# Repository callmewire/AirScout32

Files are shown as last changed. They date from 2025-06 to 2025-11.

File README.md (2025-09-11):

# AirScout32 - Mobile Air Quality Monitoring System

A complete open-source air quality monitoring solution combining ESP32-based hardware sensors with an Android application for real-time data visualization and analysis.

## 🌟 Project Overview

AirScout32 is a cost-effective, portable air quality measurement device developed as part of a Bachelor's thesis in Media Informatics. The system addresses the gap between expensive professional equipment and basic consumer devices by providing reliable multi-parameter air quality monitoring for under €100.

**Project Name**: AirScout32 reflects three core aspects:
- **Air**: Focus on air quality measurement
- **Scout**: Mobile reconnaissance and warning functionality  
- **32**: Based on the ESP32 microcontroller platform

## 📁 Repository Structure
```
AirScout32/
├── android-app/          # Android application source code
├── firmware/             # ESP32 Arduino firmware
├── hardware/             # 3D models, schematics, and assembly guides
├── docs/                 # Documentation and user manuals
└── README.md            # This file
```

## 🔧 Hardware Components

### Sensors
- **SCD40**: CO₂ measurement (400-5000 ppm) via NDIR technology
- **MiCS-5524**: VOC/CO detection with baseline calibration
- **Integrated**: Temperature and humidity monitoring

### Core System
- **ESP32 DevKit**: Dual-core microcontroller with Bluetooth/WiFi
- **18650 Li-Ion**: 8-10 hour battery life with charging management
- **Custom Enclosure**: 3D-printed dual-chamber design for thermal isolation

### Key Features
- **Autonomous alarms**: Independent safety warnings without smartphone
- **Transport stable**: No recalibration needed after movement
- **External mounting**: Prevents measurement interference from user breathing
- **Modular design**: Easy sensor expansion via I2C/analog interfaces

## 📱 Android Application

### Real-time Monitoring
- Live data visualization with interactive charts
- Bluetooth connectivity via Classic Bluetooth (SPP)
- Current values for all sensor parameters and battery status
- Configurable chart limits for performance optimization

### Session Management
- Session-based data collection with custom names
- Complete data storage independent of chart display limits
- CSV export for scientific analysis
- Metadata capture (start time, duration, data point count)

### Flexible Configuration
- Dynamic JSON mapping for different ESP32 sensor configurations
- Customizable parameter names without app recompilation
- Chart data point limitation (50-1000 points)
- User-friendly settings interface

## 🏗️ Technical Architecture

### Hardware-Software Integration
```
ESP32 Sensors → Bluetooth → Android App → Local Database → CSV Export
```

### Communication Protocol
- **Bluetooth Classic (SPP)**: Reliable connection for mobile use
- **JSON data format**: Human-readable and extensible
- **5-second intervals**: Balance between responsiveness and battery life

### Android MVVM Pattern
```
View (Fragments) ↔ ViewModel ↔ Repository (Database + Bluetooth)
```

## 📊 Supported Measurements

### Air Quality Parameters
- **CO₂**: 400-5000 ppm (±50 ppm accuracy)
- **VOCs**: Relative to baseline (MOX sensor)
- **CO**: 1-1000 ppm detection range
- **Temperature**: Integrated environmental monitoring
- **Humidity**: Relative humidity measurement

### Standard JSON Format
```json
{
  "tmp": 25.5,
  "hum": 60.2,
  "gas1": 450,
  "gas2": 320,
  "akku": 3.7
}
```

## 🚀 Getting Started

### Hardware Setup
1. **3D print enclosure** using provided STL files
2. **Assemble electronics** following wiring diagram
3. **Flash firmware** using Arduino IDE
4. **Calibrate sensors** in clean air environment

### Software Setup
1. **Install Android app** from releases or build from source
2. **Pair ESP32** in Android Bluetooth settings
3. **Configure JSON mapping** according to sensor setup
4. **Connect and start monitoring**

### Quick Start
1. Power on AirScout32 device
2. Open Android app and connect via Bluetooth
3. Monitor real-time values in Realtime tab
4. Save measurement sessions for later analysis
5. Export data as CSV for scientific evaluation

## 🔬 Scientific Applications

### Use Cases
- **Indoor air quality assessment** in homes and offices
- **Renovation monitoring** for VOC emissions
- **Workplace safety** in industrial environments
- **Educational demonstrations** of air quality concepts
- **Research data collection** for environmental studies

### Research Contributions
- Cost-effective multi-parameter air quality monitoring
- Mobile sensor platform with transport stability
- Open-source design for reproducible research
- Modular architecture for custom sensor integration

## 💾 Data Management

### Export Features
- Session metadata in CSV headers
- Timestamps in Unix and human-readable formats
- All parameters including battery status
- Android sharing for direct data transfer

### Privacy & Security
- Local data storage only (no cloud dependency)
- User-controlled data export
- Minimal permission requirements

## 📈 Performance & Reliability

### Battery Life
- **8-10 hours** continuous operation
- **2.5 hours** charging time
- **Intelligent power management**

### Measurement Accuracy
- **Factory-calibrated sensors** for CO₂
- **Baseline calibration** for relative VOC measurements
- **Transport-stable** readings without recalibration

### Build Quality
- **Dual-chamber design** prevents thermal interference
- **Heat-set inserts** for professional assembly
- **IP54-rated** for normal indoor use

## 🛠️ Development

### Building Android App
```bash
# Clone repository
git clone https://github.com/username/AirScout32
cd AirScout32/android-app

# Build debug APK
./gradlew assembleDebug

# Run tests
./gradlew test
```

### Flashing ESP32 Firmware
```bash
# Open firmware/AirScout32.ino in Arduino IDE
# Install required libraries (listed in firmware/README.md)
# Select ESP32 board and flash
```

### 3D Printing
- **Material**: PETG recommended for final version
- **Settings**: 0.2mm layer height, 30% infill
- **Post-processing**: Install heat-set inserts for assembly

*Testing**: Real-world validation in different environments

## 📚 Technologies Used

### Hardware
- **ESP32**: Espressif Systems microcontroller
- **Arduino IDE**: Firmware development environment
- **Fusion 360**: 3D CAD modeling
- **PETG/PLA**: 3D printing materials

### Software
- **Kotlin**: Android development language
- **Android Jetpack**: Modern Android architecture
- **Room Database**: Local data persistence
- **MPAndroidChart**: Real-time data visualization
- **Bluetooth Classic**: ESP32 communication

## 📄 Academic Context

Developed as part of a Bachelor's thesis in Media Informatics demonstrating:
- **IoT system integration** with mobile applications
- **Cost-effective sensor solutions** for environmental monitoring
- **User-centered design** for scientific instruments
- **Open-source hardware/software** development practices

### Thesis Contributions
- Market analysis of portable air quality monitors
- Technical evaluation of low-cost sensor technologies
- Mobile app architecture for real-time sensor data
- Validation through real-world testing scenarios

## 📊 Project Results

### Cost Analysis
- **€100 prototype cost** vs €800-2000 commercial alternatives
- **75% cost reduction** in small-scale production
- **Open-source licensing** eliminates proprietary costs

### Performance Validation
- **8.5 hour average** battery life in field tests
- **Transport-stable** measurements without recalibration
- **3.5 minute setup** time for non-technical users
- **Reliable Bluetooth** connection up to 12 meters indoors

## 📧 Contact & License

Developed for educational purposes as part of a Bachelor's thesis in Media Informatics.

**Project**: Mobile Air Quality Monitoring with ESP32 and Android  
**Institution**: Berliner Hochschule für Technik
**Year**: 2025

This project is open-source - see individual component licenses for details.

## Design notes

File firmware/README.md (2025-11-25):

# AirScout32 ESP32 Firmware

Arduino firmware for the AirScout32 air quality monitoring device.

## Hardware Requirements

### Microcontroller
- **ESP32 DevKit V1** (30-pin version)
- **Arduino IDE 2.3.6** or newer

### Sensors
- **SCD40**: CO₂, temperature, humidity (I2C)
- **MiCS-5524**: VOC/CO detection (analog)

### Additional Components
- **18650 Li-Ion battery** with protection circuit
- **Voltage divider** for battery monitoring
- **Buzzer** for audio alarms
- **LEDs** for status indication

## Pin Configuration

| Component | ESP32 Pin | Description |
|---|---|---|
| SCD41 SDA | GPIO 21 | I2C data line |
| SCD41 SCL | GPIO 22 | I2C clock line |
| MiCS-5524 | GPIO 32 | Analog VOC/CO input |
| MiCS-5524 Power | GPIO 35 | Sensor power control |
| Battery Monitor | GPIO 33 | Battery voltage (via divider) |
| Buzzer | GPIO 17 | PWM audio output |
| LED Red | GPIO 15 | Alarm indicator |
| LED Yellow | GPIO 4 | Warning indicator |
| LED Green | GPIO 16 | Status indicator |

## Required Libraries

Install these libraries through Arduino IDE Library Manager:
```
Sensirion I2C SCD4x by Sensirion AG (latest version)
ArduinoJson by Benoit Blanchon (v6.x or v7.x)
BluetoothSerial (included with ESP32 board package)
```

## Installation

1. **Install ESP32 Board Package**:
   - File → Preferences → Additional Board Manager URLs
   - Add: `https://dl.espressif.com/dl/package_esp32_index.json`
   - Tools → Board → Boards Manager → Search "ESP32" → Install

2. **Install Libraries**:
   - Sketch → Include Library → Manage Libraries
   - Install the required libraries listed above

3. **Upload Firmware**:
   - Connect ESP32 via USB
   - Select Board: "ESP32 Dev Module"
   - Select correct COM Port
   - Upload sketch

## Configuration

### Bluetooth Settings
- **Device Name**: "Sensorsender_2"
- **Profile**: SPP (Serial Port Profile)
- **Auto-connect**: Disabled (manual pairing required)

### Sensor Calibration
- **CO₂ Sensor**: Factory calibrated, no user action needed
- **VOC/CO Sensor**: Automatic baseline calibration on startup
- **Calibration Time**: 60 seconds in clean air

### Alarm Thresholds
- **CO₂ Warning**: ≥1000 ppm (yellow LED blink)
- **CO₂ Alarm**: ≥1500 ppm (yellow LED solid + audio)
- **VOC/CO Warning**: ≥150 raw ADC (red LED blink)
- **VOC/CO Alarm**: ≥200 raw ADC (red LED solid + audio)
- **Battery**: <3.5V (discharge cutoff)

## Data Output

### JSON Format
```json
{
  "CO2": 450,
  "tmp": 23.5,
  "hum": 45.2,
  "VOC+CO": 125,
  "Akku": 87.2
}
```

### Field Descriptions
- `CO2`: CO₂ concentration in ppm
- `tmp`: Temperature in °C
- `hum`: Relative humidity in %
- `VOC+CO`: VOC/CO raw ADC value (0-4095)
- `Akku`: Battery charge in %

## Operating Modes

### Normal Operation
- Green LED blinks every 5 seconds
- Continuous measurement and Bluetooth transmission
- Battery monitoring active

### Alarm Mode
- Red LED solid on
- Audio alarm (3 beeps)
- Triggered by high CO₂ or VOC levels

### Calibration Mode
- Yellow LED on during VOC baseline calibration
- Occurs automatically on startup
- Requires clean air environment

## Power Management

### Battery Life
- **Typical**: 8-10 hours continuous operation
- **Standby**: Deep sleep not implemented (continuous monitoring required)
- **Charging**: Via USB while operating

### Power Consumption
- **Active**: ~200mA average
- **CO₂ sensor**: ~20mA
- **VOC/CO sensor**: ~50mA
- **ESP32**: ~80-120mA (depending on Bluetooth activity)

## Troubleshooting

### Common Issues

**Bluetooth Not Connecting**:
- Ensure device is not paired with multiple devices
- Restart ESP32 and try pairing again
- Check if device name "Sensorsender_2" appears in scan

**Sensor Readings Unstable**:
- Allow 2-3 minutes warm-up time after power on
- Ensure stable power supply (battery >20%)
- Check I2C connections (SDA/SCL)

**VOC Values Always Zero**:
- VOC sensor needs 30-60 seconds calibration in clean air
- Restart device in well-ventilated area
- Check analog pin connection (GPIO 32)

**Battery Percentage Wrong**:
- Check voltage divider circuit
- Verify battery voltage range (3.5V-4.2V)
- Calibrate voltage measurement if needed

### Serial Monitor Debug

Enable serial monitor (115200 baud) to see:
- Sensor initialization status
- Real-time measurements
- Error messages
- Calibration progress

### LED Status Indicators

| LED Color | Status | Meaning |
|---|---|---|
| Green Blink | Normal | System operating normally |
| Yellow Solid | Calibrating | VOC sensor calibration in progress |
| Red Solid | Alarm | Air quality threshold exceeded |
| All Off | Error | Check power and connections |

## Customization

### Modifying Thresholds
Edit these values in the code:
```cpp
// CO₂ thresholds
if (co2Concentration >= 1500) // Alarm
if (co2Concentration >= 1000) // Warning

// VOC/CO thresholds (raw ADC values)
if (analogValue >= 200) // Alarm
if (analogValue >= 150) // Warning
```

### Changing Measurement Interval
```cpp
const unsigned long MEASUREMENT_INTERVAL = 5000; // milliseconds
```

### Adding New Sensors
1. Define new pin constants
2. Add initialization in `setup()`
3. Read sensor in `takeMeasurements()`
4. Add to JSON output in `sendBluetoothData()`

## Version History

- **V2.0**: Cleaned up code, improved error handling, better documentation
- **V1.2**: Added VOC baseline calibration, alarm system
- **V1.0**: Initial release with basic sensor reading

## License

Part of the AirScout32 project - see main LICENSE file.

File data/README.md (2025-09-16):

# AirScout32 Measurement Data

This directory contains the raw measurement data collected during the evaluation phase of the AirScout32 project. All datasets are provided in CSV format for maximum compatibility and reproducibility.

## Dataset Overview

| Filename | Description | Duration | Sensor Type | Test Conditions |
|---|---|---|---|---|
| `session_A_20250914_150134.csv` | Baseline measurement (empty room) | 34 minutes | SCD40 + MiCS-5524 | No occupants, closed room |
| `session_B_20250914_153851.csv` | Two-person occupancy test | 38 minutes | SCD40 + MiCS-5524 | 2 people, closed room |
| `MH-Z19_validation_data.csv` | MH-Z19 sensor validation | 22 hours | MH-Z19 + MiCS-5524 | Long-term stability test |

## Data Format

All CSV files follow the same structure exported from the AirScout32 Android application:
```csv
Session: [Session Name]
Start: [Date Time]
End: [Date Time]  
Duration: [X minutes]
Data Points: [Count]

Timestamp,Date,Time,Temperature,Humidity,Gas1,Gas2,Battery
[Unix timestamp],[Date],[Time],[°C],[%RH],[ppm/index],[index/ppm],[%]
```

### Field Descriptions

- **Timestamp**: Unix timestamp in milliseconds
- **Date**: Measurement date (YYYY-MM-DD)
- **Time**: Measurement time (HH:MM:SS)
- **Temperature**: Ambient temperature in degrees Celsius
- **Humidity**: Relative humidity in percent
- **Gas1**: CO₂ concentration in ppm (SCD40/MH-Z19 sensor)
- **Gas2**: VOC/CO index relative to baseline (MiCS-5524 sensor)
- **Battery**: Battery charge level in percent

## Test Conditions

### Session A - Baseline Measurement
- **Location**: Indoor room (4m × 5m × 2.5m = 50m³)
- **Occupancy**: Empty room
- **Ventilation**: Closed windows and doors
- **Purpose**: Establish baseline air quality values
- **Initial Conditions**: Room previously occupied, CO₂ levels stabilizing

### Session B - Occupancy Test
- **Location**: Same room as Session A
- **Occupancy**: 2 people (light activity: reading, computer work)
- **Ventilation**: Closed windows and doors
- **Purpose**: Demonstrate CO₂ accumulation with human presence
- **Termination**: Test stopped at 1973 ppm CO₂ (approaching 2000 ppm alarm threshold)

### MH-Z19 Validation Data
- **Purpose**: Long-term sensor validation and stability assessment
- **Sensor**: MH-Z19 NDIR CO₂ sensor for reference comparison
- **Duration**: 22 hours (1320 minutes) with sparse data collection
- **Conditions**: Extended operation test
- **Note**: Only Gas1 (CO₂) values recorded (473-816 ppm range), other parameters set to 0.0

## Data Usage

These datasets can be used to:
- Reproduce the analysis presented in the thesis
- Validate the AirScout32 system performance
- Compare different sensor technologies (SCD40 vs MH-Z19)
- Analyze indoor air quality patterns
- Develop or test data analysis algorithms

## Data Quality Notes

- Measurement interval: Approximately 10-11 seconds between data points
- Sensor warm-up: First 2-3 minutes may show stabilization behavior
- VOC baseline: MiCS-5524 sensor uses relative measurements (baseline = 100)
- CO₂ accuracy: ±50 ppm (manufacturer specification for SCD40 and MH-Z19)

## Reproducibility

To reproduce the measurements:
1. Use AirScout32 hardware with SCD40 and MiCS-5524 sensors
2. Follow test conditions as described above
3. Use the Android application for data collection
4. Export sessions in CSV format

## Citation

When using this data, please cite:
```
Uhlmann, P. (2024). AirScout32 Measurement Data. 
Bachelor's Thesis: Mobile Air Quality Monitoring with ESP32 and Android.
Available at: https://github.com/callmewire/AirScout32
```

## Contact

For questions about the data or measurement procedures, please refer to the main thesis document or open an issue in the repository.

## License

This data is provided under the same license as the main AirScout32 project. See the main LICENSE file for details.

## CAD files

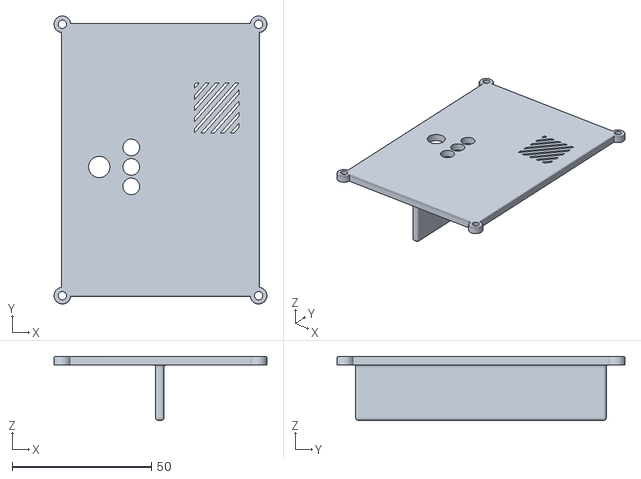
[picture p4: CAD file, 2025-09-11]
hardware/3d-models/AIrscout 32 lid v3.stl
76.5 x 103.5 x 23.0

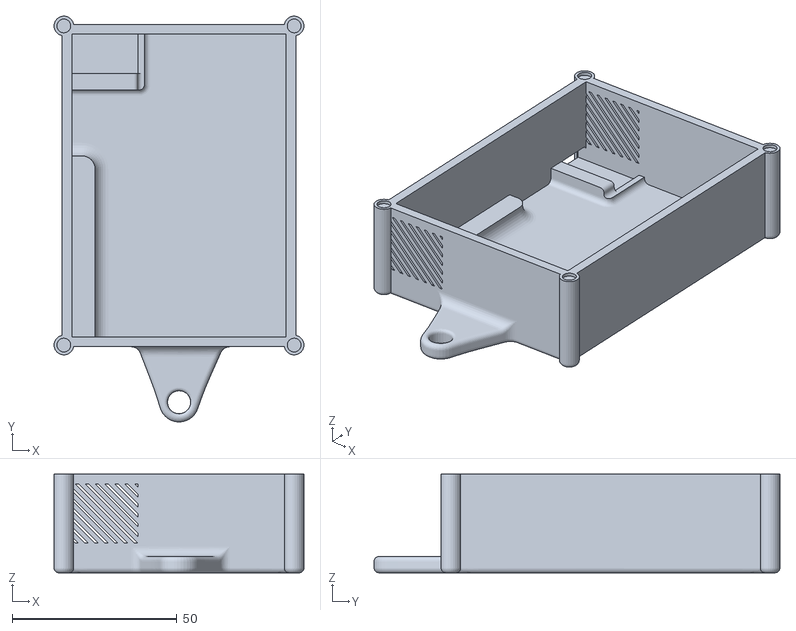
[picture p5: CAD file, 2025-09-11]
hardware/3d-models/Airscout 32 Bottom v2.stl
76.0 x 123.4 x 30.0

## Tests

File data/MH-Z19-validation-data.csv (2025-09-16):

Session: Session 05.08.2025 09:59
Start: 04.08.2025 11:59:37
End: 05.08.2025 09:59:41
Duration: 1320 minutes
Data Points: 88
Timestamp | Date | Time | Temperature | Humidity | Gas1 | Gas2 | Battery
1754301577066 | 2025-08-04 | 11:59:37 | 0.0 | 0.0 | 806.0 | 0.0 | 0.0
1754301582999 | 2025-08-04 | 11:59:42 | 0.0 | 0.0 | 806.0 | 0.0 | 0.0
1754301589502 | 2025-08-04 | 11:59:49 | 0.0 | 0.0 | 806.0 | 0.0 | 0.0
1754301596864 | 2025-08-04 | 11:59:56 | 0.0 | 0.0 | 806.0 | 0.0 | 0.0
1754301600932 | 2025-08-04 | 12:00:00 | 0.0 | 0.0 | 816.0 | 0.0 | 0.0
1754301613988 | 2025-08-04 | 12:00:13 | 0.0 | 0.0 | 811.0 | 0.0 | 0.0
1754376770787 | 2025-08-05 | 08:52:50 | 0.0 | 0.0 | 502.0 | 0.0 | 0.0
1754376776876 | 2025-08-05 | 08:52:56 | 0.0 | 0.0 | 502.0 | 0.0 | 0.0
1754376782817 | 2025-08-05 | 08:53:02 | 0.0 | 0.0 | 502.0 | 0.0 | 0.0
1754376788758 | 2025-08-05 | 08:53:08 | 0.0 | 0.0 | 502.0 | 0.0 | 0.0
1754376794690 | 2025-08-05 | 08:53:14 | 0.0 | 0.0 | 502.0 | 0.0 | 0.0
1754376800686 | 2025-08-05 | 08:53:20 | 0.0 | 0.0 | 502.0 | 0.0 | 0.0
1754376807069 | 2025-08-05 | 08:53:27 | 0.0 | 0.0 | 502.0 | 0.0 | 0.0
1754376812691 | 2025-08-05 | 08:53:32 | 0.0 | 0.0 | 512.0 | 0.0 | 0.0
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

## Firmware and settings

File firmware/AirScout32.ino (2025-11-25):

/**
 * AirScout32 - Air Quality Monitoring System
 * 
 * Measures CO2, temperature, humidity (SCD41), and VOC/CO (MICS5524).
 * Transmits data via Bluetooth as JSON. Provides LED and audio warnings.
 * 
 * Author:  Paul Uhlmann
 * Date:    2025-11-25
 * Version: 1.2.40
 * Board:   ESP32
 */

#include <Arduino.h>
#include <SensirionI2cScd4x.h>
#include <Wire.h>
#include "DFRobot_MICS.h"
#include "BluetoothSerial.h"    // v1.1.0
#include "ArduinoJson.h"        // v7.4.1

BluetoothSerial SerialBT;

// Battery config (Li-Ion via 1:2 voltage divider on GPIO 33)
const int ubPin = 2;
const float Ubmax = 4.2;  // Max voltage (full)
const float Ubmin = 3.5;  // Min voltage (empty)

// MICS5524 gas sensor pins
#define CALIBRATION_TIME   2
#define ADC_PIN            32
#define POWER_PIN          35
#define ANALOG_PIN         33

DFRobot_MICS_ADC mics(ADC_PIN, POWER_PIN);

#ifdef NO_ERROR
#undef NO_ERROR
#endif
#define NO_ERROR 0

// LED pins
const int rotLed = 15;    // Red - danger
const int gelbLed = 4;    // Yellow - warning
const int grünLed = 16;   // Green - status

// Global variables
int ubValue = 0;
int analogPin = 33;
int sensorValue = 0;
float analogVoltage = 0.00;
const int Lautsprecher_Pin = 17;

SensirionI2cScd4x sensor;
static char errorMessage[64];
static int16_t error;

// Print 64-bit hex value (for sensor serial number)
void PrintUint64(uint64_t& value) {
  Serial.print("0x");
  Serial.print((uint32_t)(value >> 32), HEX);
  Serial.print((uint32_t)(value & 0xFFFFFFFF), HEX);
}

void setup() {
  Serial.begin(115200);
  while (!Serial) {
    delay(100);
  }
  
  Wire.begin();
  sensor.begin(Wire, SCD41_I2C_ADDR_62);

  uint64_t serialNumber = 0;
  delay(30);
  
  // Initialize SCD41 sensor
  error = sensor.wakeUp();
  if (error != NO_ERROR) {
    Serial.print("Error wakeUp(): ");
    errorToString(error, errorMessage, sizeof errorMessage);
    Serial.println(errorMessage);
  }
  
  error = sensor.stopPeriodicMeasurement();
  if (error != NO_ERROR) {
    Serial.print("Error stopPeriodicMeasurement(): ");
    errorToString(error, errorMessage, sizeof errorMessage);
    Serial.println(errorMessage);
  }
  
  error = sensor.reinit();
  if (error != NO_ERROR) {
    Serial.print("Error reinit(): ");
    errorToString(error, errorMessage, sizeof errorMessage);
    Serial.println(errorMessage);
  }
  
  error = sensor.getSerialNumber(serialNumber);
  if (error != NO_ERROR) {
    Serial.print("Error getSerialNumber(): ");
    errorToString(error, errorMessage, sizeof errorMessage);
    Serial.println(errorMessage);
    return;
  }
  Serial.print("Serial number: ");
  PrintUint64(serialNumber);
  Serial.println();

  // Initialize Bluetooth
  SerialBT.begin("Sensorsender_2");
  Serial.println("Bluetooth ready. Device: Sensorsender_2");

  // Initialize LEDs and speaker
  pinMode(rotLed, OUTPUT);
  pinMode(gelbLed, OUTPUT);
  pinMode(grünLed, OUTPUT);
  
  tone(Lautsprecher_Pin, 800, 500);
  
  // Warm-up sequence (~30s)
  for (int i = 0; i <= 10; i++) {
       digitalWrite(grünLed, HIGH);
       delay(500);
       digitalWrite(grünLed, LOW);
       delay(100);
       digitalWrite(gelbLed, HIGH);
       delay(500);
       digitalWrite(gelbLed, LOW);
       delay(100);
       digitalWrite(rotLed, HIGH);
       delay(500);
       digitalWrite(rotLed, LOW);
       delay(100);
       digitalWrite(gelbLed, HIGH);
       delay(500);
       digitalWrite(gelbLed, LOW);
       delay(100);
    digitalWrite(grünLed, HIGH);
  }
  
  // Ready melody
  tone(Lautsprecher_Pin, 1000, 1000);
  tone(Lautsprecher_Pin, 800, 1000);
  tone(Lautsprecher_Pin, 1000, 1000);
  tone(Lautsprecher_Pin, 800, 1000);
  
  Serial.println("Initialization complete.");
}

void loop() {
  uint16_t co2Concentration = 0;
  float temperature = 0;
  float relativeHumidity = 0;

  // Wake sensor and take measurement
  error = sensor.wakeUp();
  if (error != NO_ERROR) {
    Serial.print("Error wakeUp(): ");
    errorToString(error, errorMessage, sizeof errorMessage);
    Serial.println(errorMessage);
    return;
  }
  
  // Discard first measurement after wake-up
  error = sensor.measureSingleShot();
  if (error != NO_ERROR) {
    Serial.print("Error measureSingleShot(): ");
    errorToString(error, errorMessage, sizeof errorMessage);
    Serial.println(errorMessage);
    return;
  }
  
  error = sensor.measureAndReadSingleShot(co2Concentration, temperature, relativeHumidity);
  if (error != NO_ERROR) {
    Serial.print("Error measureAndReadSingleShot(): ");
    errorToString(error, errorMessage, sizeof errorMessage);
    Serial.println(errorMessage);
    return;
  }
  
  // Debug output
  Serial.print("CO2 [ppm]: ");
  Serial.println(co2Concentration);
  Serial.print("Temperature [°C]: ");
  Serial.println(temperature, 1);
  Serial.print("Humidity [%RH]: ");
  Serial.println(relativeHumidity, 0);
  
  delay(30);
  
  // Read MICS5524 (VOC/CO)
  int analogValue = analogRead(ADC_PIN);
  Serial.print("VOC (raw): ");
  Serial.println(analogValue);
  
  // Read battery voltage (1:2 divider, 3.74V ref, 12-bit ADC)
  int ubvalue = analogRead(ANALOG_PIN);
  analogVoltage = ubvalue * 2 * (3.74 / 4095.0);
  Serial.print("Battery: ");
  Serial.print(analogVoltage);
  Serial.println("V");
  
  // Calculate battery percentage (4.2V=100%, 3.5V=0%)
  float percent = constrain((analogVoltage - Ubmin) / (Ubmax - Ubmin) * 100.0, 0.0, 100.0);
  Serial.print("Battery: ");
  Serial.print(percent, 0);
  Serial.println("%");

  // Send JSON via Bluetooth
  StaticJsonDocument<200> doc;
  doc["CO2"] = (float)co2Concentration;
  doc["tmp"] = temperature;
  doc["hum"] = relativeHumidity;
  doc["VOC+CO"] = (float)analogValue;
  doc["Akku"] = percent;
  
  String output;
  serializeJson(doc, output);
  SerialBT.println(output);

  // CO2 warning (1000ppm = warning, 1500ppm = alarm)
  if (co2Concentration >= 1500) {
    digitalWrite(gelbLed, HIGH);
    tone(Lautsprecher_Pin, 820, 200);
    tone(Lautsprecher_Pin, 660, 200);
    tone(Lautsprecher_Pin, 820, 200);
    tone(Lautsprecher_Pin, 660, 200);
  } else if (co2Concentration >= 1000) {
    digitalWrite(gelbLed, HIGH);
    delay(500);
    digitalWrite(gelbLed, LOW);
    delay(500);
  } else {
    digitalWrite(gelbLed, LOW);
  }

  // VOC/CO warning (150 = warning, 200 = alarm)
  if (analogValue >= 200) {
    digitalWrite(rotLed, HIGH);
    tone(Lautsprecher_Pin, 820, 200);
    tone(Lautsprecher_Pin, 660, 200);
    tone(Lautsprecher_Pin, 820, 200);
    tone(Lautsprecher_Pin, 660, 200);
  } else if (analogValue >= 150) {
    digitalWrite(rotLed, HIGH);
    delay(500);
    digitalWrite(rotLed, LOW);
    delay(500);
  } else {
    digitalWrite(rotLed, LOW);
  }


  // Detailed gas readings from MICS5524
  float coConcentration = mics.getGasData(CO);
  float ch4Concentration = mics.getGasData(CH4);
  float c2h5ohConcentration = mics.getGasData(C2H5OH);
  float h2Concentration = mics.getGasData(H2);
  float nh3Concentration = mics.getGasData(NH3);
  float no2Concentration = mics.getGasData(NO2);

  Serial.print("CO: ");
  Serial.print(coConcentration, 1);
  Serial.println(" PPM");
  Serial.print("CH4: ");
  Serial.print(ch4Concentration, 1);
  Serial.println(" PPM");
  Serial.print("C2H5OH: ");
  Serial.print(c2h5ohConcentration, 1);
  Serial.println(" PPM");
  Serial.print("H2: ");
  Serial.print(h2Concentration, 1);
  Serial.println(" PPM");
  Serial.print("NH3: ");
  Serial.print(nh3Concentration, 1);
  Serial.println(" PPM");
  Serial.print("NO2: ");
  Serial.print(no2Concentration, 1);
  Serial.println(" PPM");
  Serial.println();

  delay(1000);
}

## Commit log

2025-06-18 added basic app prototype
2025-07-24 added better battery user experience and changed input json
2025-09-11 restructuring like everything
    [AIrscout 32 lid v3.stl, Airscout 32 Bottom v2.stl]
2025-09-16 add test mesurements
    [MH-Z19-validation-data.csv, session_A_20250914_150134.csv, session_B_20250914_153851.csv]
2025-11-25 updated firmware for led usage
